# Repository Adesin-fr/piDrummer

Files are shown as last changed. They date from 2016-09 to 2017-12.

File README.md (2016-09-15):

# piDrummer

piDrummer is a DIY drum trigger device. it uses an Arduino and some basic components to get the signal from your pads (AKA triggers) and send them to a Raspberry Pi 3.

A Raspberry Pi 3 is used to play sounds according to the triggers you hit. 

Thanks to CPU power of a such board computer (4x1.2 Ghz), it is possible to play the best sound quality !

The rPi is also driving an ILI9341 TFT screen (320x240 pixels, can be found as cheap as 5$ on ebay ) and displays an interface that allows you to set up your different drum kits, the volume, sound effects (reverb, equalizer, etc...), and map each trigger to an instrument.

The goal is also to build an embedded linux, with the smallest possible kernel, allowing for very small boot time !

# piDrummer (Version Française)

piDrummer est un module de batterie électronique à fabriquer soi-même.

Il utilise un module Arduino et quelques composants pour récupérer le signal depuis les PADS (aussi appelés Triggers), et envoie ces informations à une carte Raspberry Pi 3.

La carte est alors utilisée pour jouer les sons en fonction des coups donnés.

Grâce à la puissance de calcul disponible sur la carte (4x1.2 Ghz), un rendu sonore de haute qualité est possible !

La carte rPi est aussi utilisée pour piloter un afficheur TFT (320x240 à base de puce ILI9341, qu'on peut acheter sur Ebay pour moins de 5€) afin de régler et choisir vos différents kits, le volume, les effets sonores (reverb, équaliseur, etc...) et mapper chaque trigger à un instrument.

Le but du projet est aussi de monter un système linux embarqué (linux Embedded) avec un noyau le plus léger possible, et un temps de démarrage le plus faible possible !

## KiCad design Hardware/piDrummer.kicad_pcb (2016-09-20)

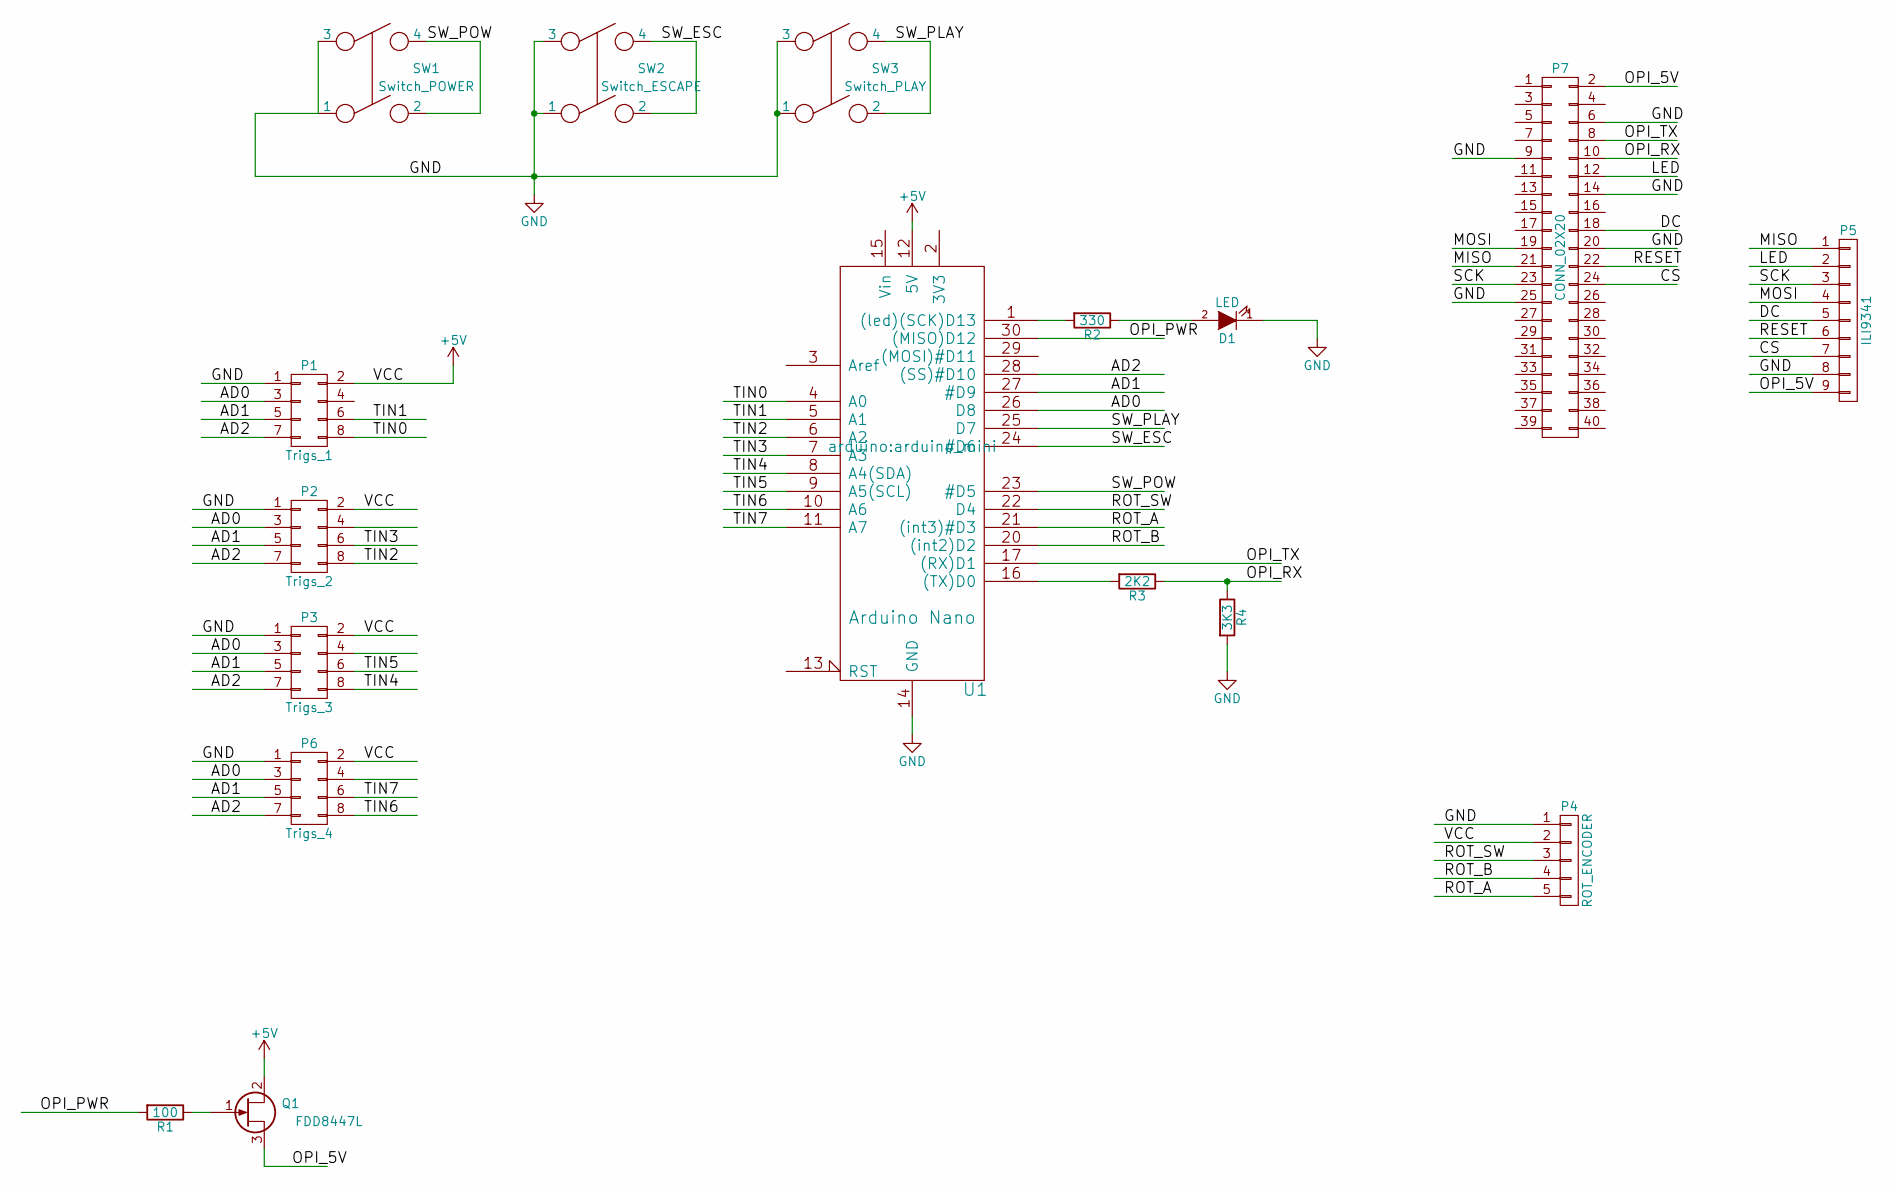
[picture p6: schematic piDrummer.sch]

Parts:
D1: LED; LED-3MM
P1: Trigs_1; Pin_Header_Straight_2x04
P2: Trigs_2; Pin_Header_Straight_2x04
P3: Trigs_3; Pin_Header_Straight_2x04
P4: ROT_ENCODER; Pin_Header_Straight_1x05
P5: ILI9341; Pin_Header_Straight_1x09
P6: Trigs_4; Pin_Header_Straight_2x04
P7: CONN_02X20; Pin_Header_Straight_2x20
Q1: FDD8447L; MOSFET_TO252
R1: 100; R4-LARGE_PADS
R2: 330; R4-LARGE_PADS
R3: 2K2; R4-LARGE_PADS
R4: 3K3; R4-LARGE_PADS
SW1: Switch_POWER; NetTie-III
SW2: Switch_ESCAPE; NetTie-III
SW3: Switch_PLAY; NetTie-III
U1: Arduino Nano; arduino_mini

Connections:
+5V: P1.2, P2.2, P3.2, P4.2, P6.2, Q1.2 (D), U1.12 (5V)
/AD0: P1.3, P2.3, P3.3, P6.3, U1.26 (D8)
/AD1: P1.5, P2.5, P3.5, P6.5, U1.27 (#D9)
/AD2: P1.7, P2.7, P3.7, P6.7, U1.28 ((SS)#D10)
/CS: P5.7, P7.24
/DC: P5.5, P7.18
/LED: P5.2, P7.12
/MISO: P5.1, P7.21
/MOSI: P5.4, P7.19
/OPI_5V: P5.9, P7.2, Q1.3 (S)
/OPI_PWR: R1.2, U1.30 ((MISO)D12)
/OPI_RX: P7.10, R3.1, R4.1
/OPI_TX: P7.8, U1.17 ((RX)D1)
/RESET: P5.6, P7.22
/ROT_A: P4.5, U1.21 ((int3)#D3)
/ROT_B: P4.4, U1.20 ((int2)D2)
/ROT_SW: P4.3, U1.22 (D4)
/SCK: P5.3, P7.23
/SW_ESC: SW2.2, SW2.4, U1.24 (#D6)
/SW_PLAY: SW3.2, SW3.4, U1.25 (D7)
/SW_POW: SW1.2, SW1.4, U1.23 (#D5)
/TIN0: P1.8, U1.4 (A0)
/TIN1: P1.6, U1.5 (A1)
/TIN2: P2.8, U1.6 (A2)
/TIN3: P2.6, U1.7 (A3)
/TIN4: P3.8, U1.8 (A4(SDA))
/TIN5: P3.6, U1.9 (A5(SCL))
/TIN6: P6.8, U1.10 (A6)
/TIN7: P6.6, U1.11 (A7)
GND: D1.1 (K), P1.1, P2.1, P3.1, P4.1, P5.8, P6.1, P7.6, P7.9, P7.14, P7.20, P7.25, R4.2, SW1.1, SW1.3, SW2.1, SW2.3, SW3.1, SW3.3, U1.14 (GND), U1.19 (GND)
unnamed: D1.2 (A), R2.1
unnamed: Q1.1 (G), R1.1
unnamed: R2.2, U1.1 ((led)(SCK)D13)
unnamed: R3.2, U1.16 ((TX)D0)

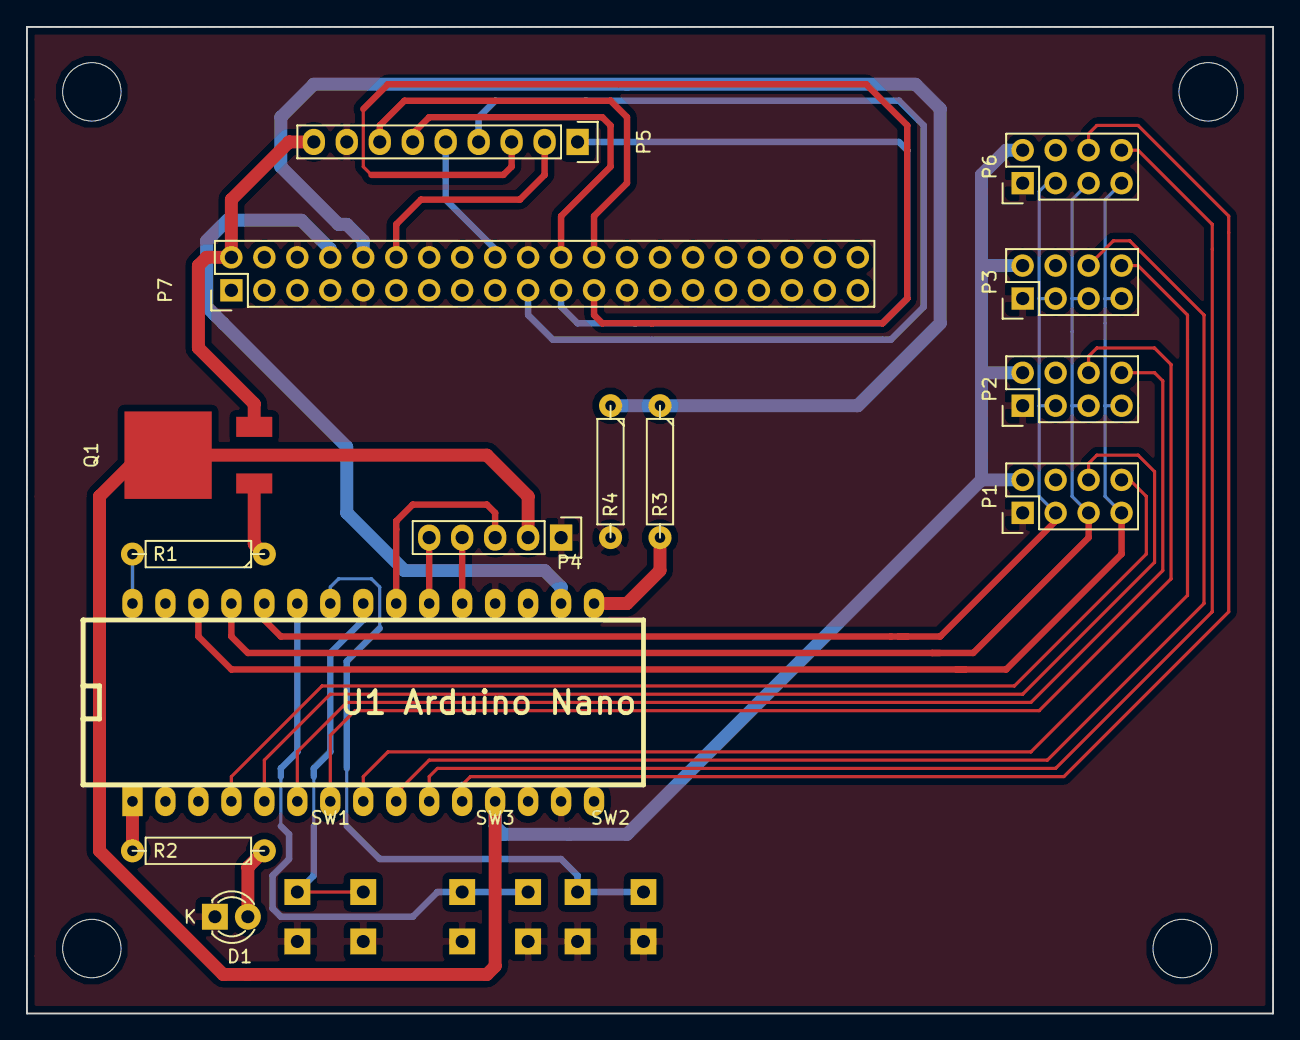
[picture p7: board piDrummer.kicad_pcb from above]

Board: 2 copper layers, 96.0 x 76.0 mm, 17 parts (0 on the bottom side), 34 nets.

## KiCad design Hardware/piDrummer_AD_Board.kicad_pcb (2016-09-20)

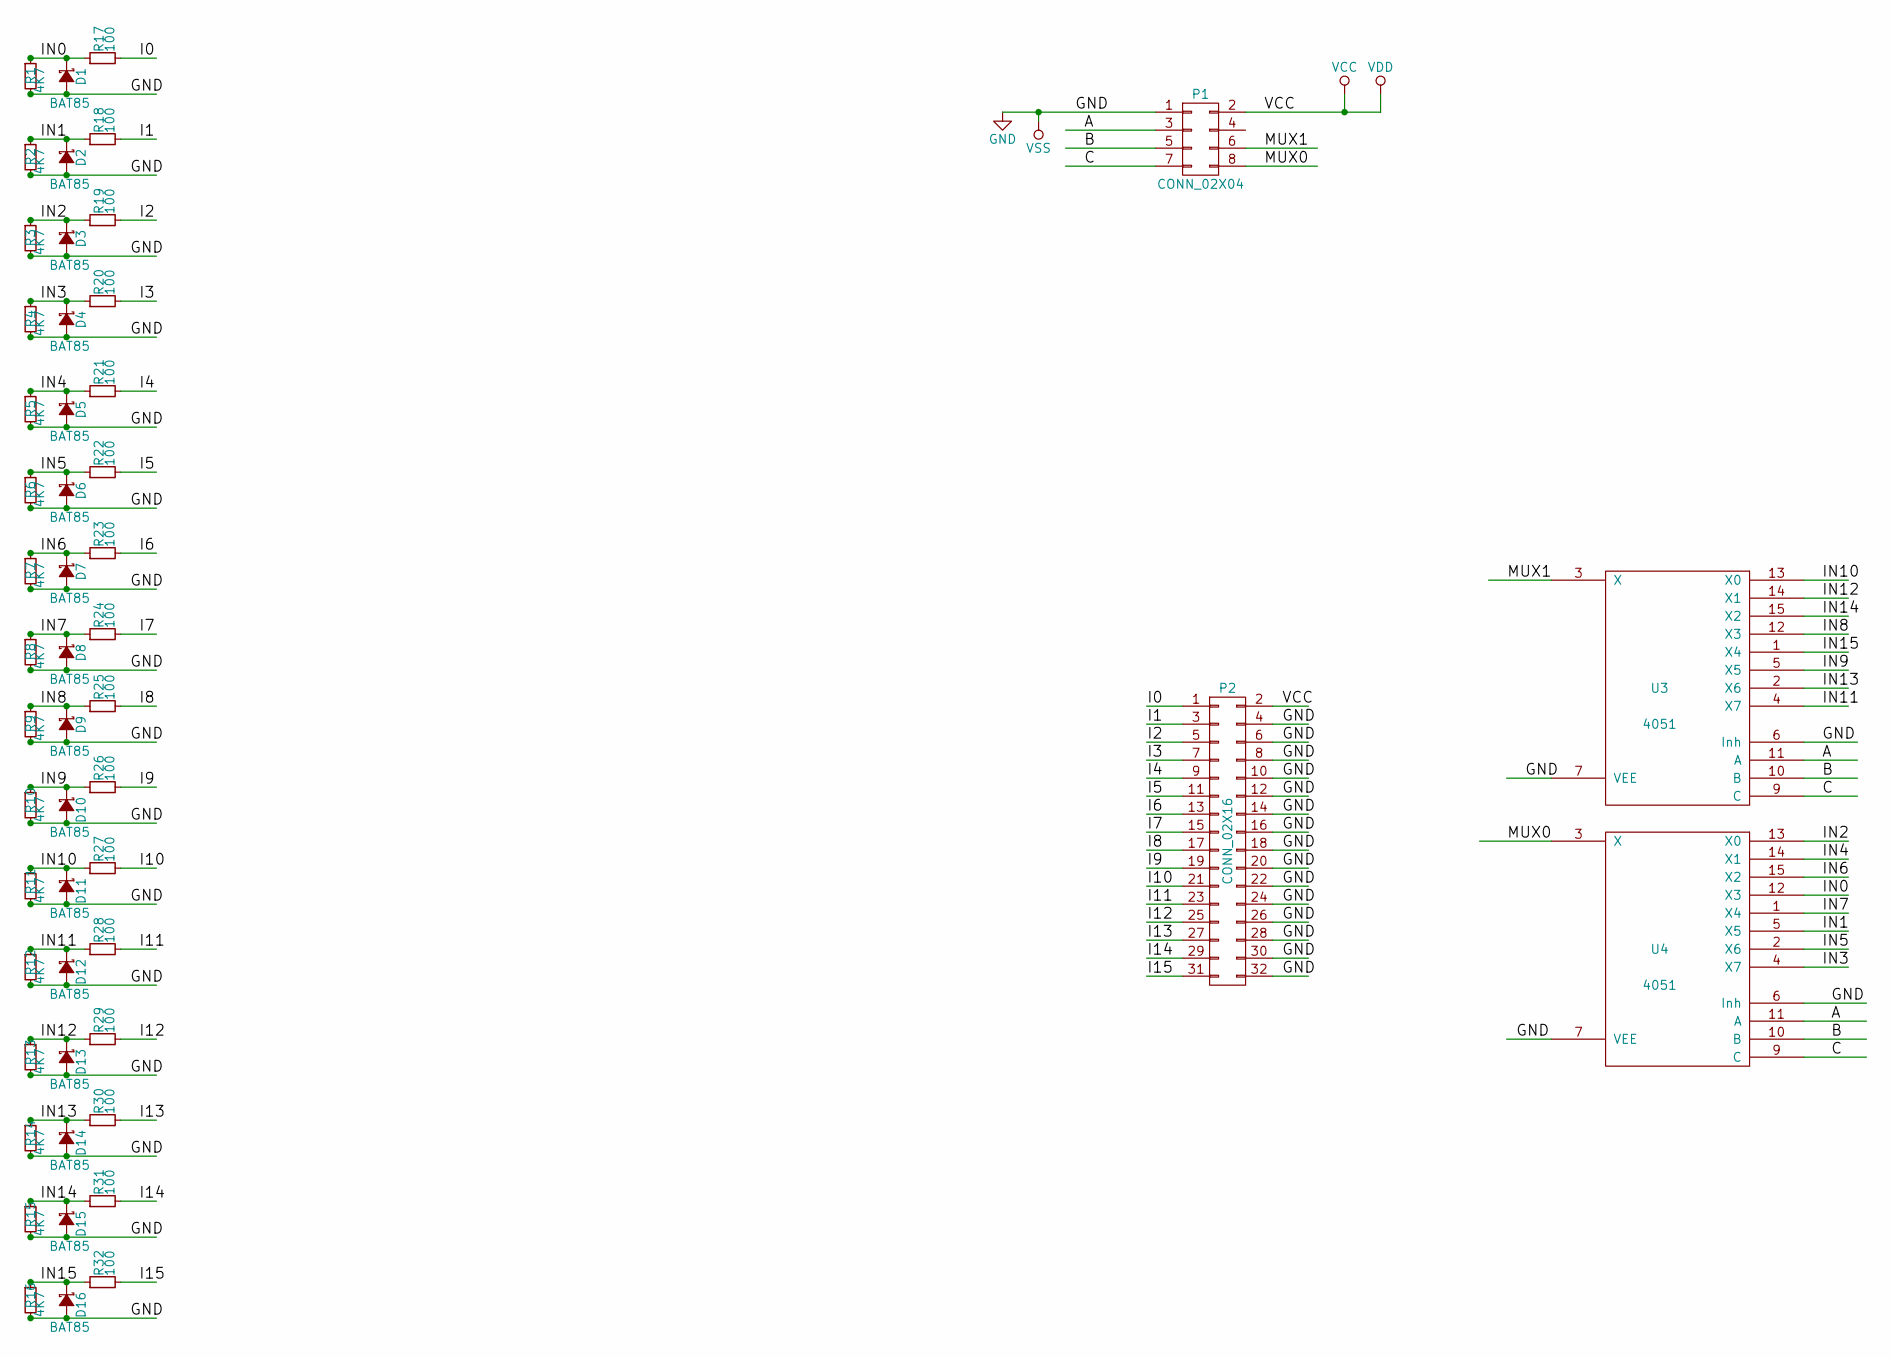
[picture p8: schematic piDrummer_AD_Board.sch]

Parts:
D1, D2, D3, D4, D5, D6, D7, D8, D9, D10, D11, D12, D13, D14, D15, D16: BAT85; Diode_DO-35_SOD27_Horizontal_RM10
P1: CONN_02X04; Header_Straight_8pins
P2: CONN_02X16; Header_Straight_32pins
R1, R2, R3, R4, R5, R6, R7, R8, R9, R10, R11, R12, R13, R14, R15, R16: 4K7; RES35
R17, R18, R19, R20, R21, R22, R23, R24, R25, R26, R27, R28, R29, R30, R31, R32: 100; RES35
U3, U4: 4051; DIP-16_W7.62mm_LongPads

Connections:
/A: P1.3, U3.11 (A), U4.11 (A)
/B: P1.5, U3.10 (B), U4.10 (B)
/C: P1.7, U3.9 (C), U4.9 (C)
/I0: P2.1, R17.2
/I1: P2.3, R18.2
/I2: P2.5, R19.2
/I3: P2.7, R20.2
/I4: P2.9, R21.2
/I5: P2.11, R22.2
/I6: P2.13, R23.2
/I7: P2.15, R24.2
/I8: P2.17, R25.2
/I9: P2.19, R26.2
/I10: P2.21, R27.2
/I11: P2.23, R28.2
/I12: P2.25, R29.2
/I13: P2.27, R30.2
/I14: P2.29, R31.2
/I15: P2.31, R32.2
/IN0: D1.1 (K), R1.1, R17.1, U4.12 (X3)
/IN1: D2.1 (K), R2.1, R18.1, U4.5 (X5)
/IN2: D3.1 (K), R3.1, R19.1, U4.13 (X0)
/IN3: D4.1 (K), R4.1, R20.1, U4.4 (X7)
/IN4: D5.1 (K), R5.1, R21.1, U4.14 (X1)
/IN5: D6.1 (K), R6.1, R22.1, U4.2 (X6)
/IN6: D7.1 (K), R7.1, R23.1, U4.15 (X2)
/IN7: D8.1 (K), R8.1, R24.1, U4.1 (X4)
/IN8: D9.1 (K), R9.1, R25.1, U3.12 (X3)
/IN9: D10.1 (K), R10.1, R26.1, U3.5 (X5)
/IN10: D11.1 (K), R11.1, R27.1, U3.13 (X0)
/IN11: D12.1 (K), R12.1, R28.1, U3.4 (X7)
/IN12: D13.1 (K), R13.1, R29.1, U3.14 (X1)
/IN13: D14.1 (K), R14.1, R30.1, U3.2 (X6)
/IN14: D15.1 (K), R15.1, R31.1, U3.15 (X2)
/IN15: D16.1 (K), R16.1, R32.1, U3.1 (X4)
/MUX0: P1.8, U4.3 (X)
/MUX1: P1.6, U3.3 (X)
GND: D1.2 (A), D2.2 (A), D3.2 (A), D4.2 (A), D5.2 (A), D6.2 (A), D7.2 (A), D8.2 (A), D9.2 (A), D10.2 (A), D11.2 (A), D12.2 (A), D13.2 (A), D14.2 (A), D15.2 (A), D16.2 (A), P1.1, P2.4, P2.6, P2.8, P2.10, P2.12, P2.14, P2.16, P2.18, P2.20, P2.22, P2.24, P2.26, P2.28, P2.30, P2.32, R1.2, R2.2, R3.2, R4.2, R5.2, R6.2, R7.2, R8.2, R9.2, R10.2, R11.2, R12.2, R13.2, R14.2, R15.2, R16.2, U3.6 (Inh), U3.7 (VEE), U3.8 (VSS), U4.6 (Inh), U4.7 (VEE), U4.8 (VSS)
VCC: P1.2, P2.2, U3.16 (VDD), U4.16 (VDD)

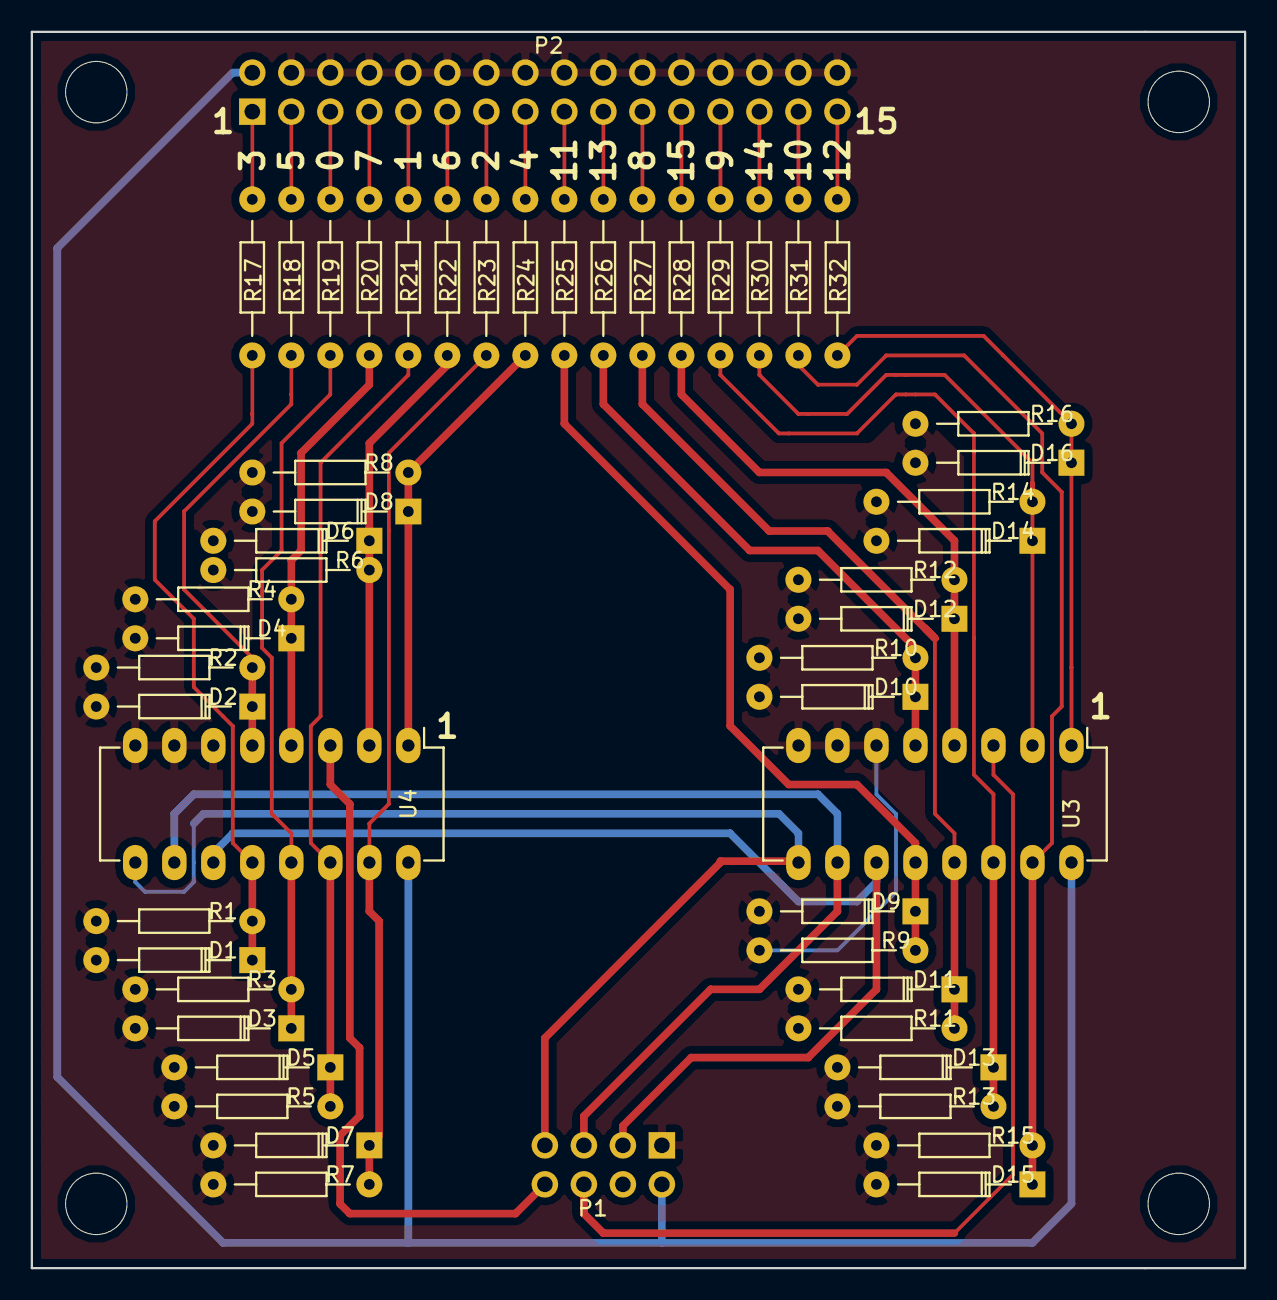
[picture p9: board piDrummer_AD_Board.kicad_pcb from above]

Board: 2 copper layers, 79.0 x 80.5 mm, 52 parts (0 on the bottom side), 39 nets.

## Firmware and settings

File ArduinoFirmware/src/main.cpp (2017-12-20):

#include <Arduino.h>
#include <EEPROM.h>
#include "piDrummer.h"
#include "encoder.h"

/*
 * POWER Button behavior :
 * 		When we power the arduino, we are on standby mode. > MOSFET is OFF, POWER LED is OFF
 *		If we push the power button :
 *			turn ON the MOSFET
 *			blink the LED until the OrangePI sends "ready status" and get parameters
 *		If we push the button before ready status : do nothing
 *		If we push the button after ready status :
 * 			blink led while not ready to poweroff (a few seconds)
 *			send POWEROFF event to OrangePI
 *			wait a few seconds and MOSFET OFF
 *		If receive a POWEROFF event from OrangePI :
 *			do POWEROFF sequence.
 *
 * TODO :
 * - Handle serial inputs to set parameters for each trigger.
	"CT",m_crossTalkGroup);
	"DT",m_dynamicTriggerPercent);
	"FS",m_footSplashSensitivity);
	"CR",m_ControllerResolution);
	"MG",m_muteGroup);
	"MT",m_FixedMaskTime);
	"TH",m_threshold);
	"TT",m_triggerType);
	"MV",m_maxValue);
 *
 * - Cymbal 3 zones w/ Chocke :  ?
 * 		> Voir fichier cy-15r.gif pour cablage & principe
 * 			3 entrées :
 * 			> 1 piezo = velocité
 * 			> 1 switch bell / 1 switch underside (choke) en parallele
 * 				> Maintient appuyé sur switch = choke
 * 			> 1 switch edge
 *
 * 		> Frappe courte sur switch bell/edge = envoi note bell/edge
 *
 * - Pour les entrées SWITCH : activer resistance PULL-UP : digitalWrite(A0, HIGH);
 * - Parametre par entree : type PAD / SWITCH
 * - FAIRE UN TEST AVEC TOUTES LES PULLUP ?
 * - Implement HiHat "Chicks" (record time between pedal value variation )
 * - Implement Cross-Talk groups (i.e. for cymbal dual zone handling)
 */

Trigger trigArray[NB_ANALOG_CHANNELS];

int anaRead=0;
int lastHitRawValue;
byte midiVelocity=0;
byte lastHitTrigger=0;
byte HiHatPedalChannel=16;
byte HiHatCymbalChannel=17;
byte HiHatValue=0;
byte prevHiHatValue;
bool isPowerON=false;
bool isOPiReady=false;
bool PowerLedState=false;
bool PowerOffAsked=false;
unsigned long lastPowerButtonPress=0;
unsigned long lastPowerLedBlinkTime=0;
unsigned long PowerOffAskTime=0;
unsigned int encoder0Pos = 0;
int oldEncoderPos = 0;

void setup() {
	Serial.begin(115200);

	// Faster ADC readings :
	setADCSampleRate();


	pinMode(MUXER_AD0, OUTPUT)   ; // Muxer address select PINs
	pinMode(MUXER_AD1, OUTPUT)   ; // Muxer address select PINs
	pinMode(MUXER_AD2, OUTPUT)   ; // Muxer address select PINs
	pinMode(encoderPinA, INPUT_PULLUP);
	pinMode(encoderPinB, INPUT_PULLUP);
	pinMode(EnterPushButton, INPUT_PULLUP);
	pinMode(EscapePushButton, INPUT_PULLUP);
	pinMode(POWER_BUTTON_PIN, INPUT_PULLUP);


		/*
		// Perform auto-threshold

		// Read each channel 20 times, sum the values, then divide them to get the average value:
		long readValue[NB_ANALOG_CHANNELS];
		for (int i=1; i<=NB_ANALOG_CHANNELS; i++){
			readValue[i]=0;
		}

		for (int count=0; count<20; count++) {
			for (int i=0; i<NB_ANALOG_CHANNELS; i++){
				// Read the channel and add th result to the array :
				byte tempValue=readChannel(i);
				readValue[i]+=tempValue;
				// Wait 10 ms between each channel reading...
				delay (10);
			}
		}

		// Once we're done with readings, divide the values and store them in config :
		for (int i=0; i<NB_ANALOG_CHANNELS; i++){
			// Read the channel and add th result to the array :
			if (i != HiHatPedalChannel){
				// Don't apply threshold to hihat channel
				byte tempValue=readValue[i] / 20;
				trigArray[i].thresHold = tempValue;
			}
		}
		*/



		for (int i=0; i<NB_ANALOG_CHANNELS; i++){

			trigArray[i].thresHold = 25;
			trigArray[i].debounce=20;
			trigArray[i].DynamicThreshold=20;
			trigArray[i].maxValue=1023;
		}


}




void loop() {


		doAnalogReadings();

		// Deal with Encoder values :
		HandleEncoderChange();

	// Deal with trigger events only if OPi is Ready !
	if (isOPiReady){

		// Deal with Encoder values :
		HandleEncoderChange();

		// Deal with inputs :
		doAnalogReadings();

		// Reset Threshold values :
		ResetThresholdValues();
	}

	// Handle POWER button  :
	if (lastPowerButtonPress+100 < millis() && digitalRead(POWER_BUTTON_PIN)==LOW){
		Serial.println("Pow !");
		lastPowerButtonPress = millis();
		// Button was pressed : do something !
		if (isPowerON==false){
			// We are not powered , let's go ON !
			isPowerON=true;
			// Turn on the led...
			PowerLedState=true;
			digitalWrite(POWER_MOSFET_PIN, HIGH);
			digitalWrite(POWER_LED_PIN, PowerLedState);
		}else{
			// We are powered , let's go OFF (if we can...)
			// If we are powered ON, but the OrangiPI is not ready, do nothing...
			if (isOPiReady){
				isOPiReady=false;
				PowerOffAsked=true;
				// Since isOpiReady==false AND isPowerON==true, the LED should start blinking !
				// Send the OPi a signal to ask him shut-off...
				// Equivalent to F12 key value !
				serialOut(MSGTYPE_KEYPRESS_VALUE, 255, 38, 0);
			}
		}
	}

	// Should we blink the led ?
	if (isPowerON && !isOPiReady && lastPowerLedBlinkTime+1000 < millis()){
			PowerLedState=!PowerLedState;
			digitalWrite(POWER_LED_PIN, PowerLedState);
	}

	// Should we shut power to the oPi ?
	if (PowerOffAskTime+10000 < millis() && PowerOffAsked==true){
		PowerOffAsked=false;
		isPowerON=false;
		// Switch off power supply now :
		digitalWrite(POWER_MOSFET_PIN, LOW);
	}

}

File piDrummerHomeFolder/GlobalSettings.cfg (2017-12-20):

AlsaBufferSize = 2048;
numTriggerInput = 32;
GlobalVolume = 32;
AutoPowerOffDelay = 0;
ReverbDelay = 0;
PowerOnKitName = "Basic Kit";
SerialDevice = "";
GlobalFadeOutTime = 0.5;
PlaySampleOnSettingChange = true;
RotaryKnobInversion = false;
RotaryKnobAction = 2;
EQLowFrequency = 0;
EQMidFrequency = 0;
EQHiFrequency = 0;
EQLowGain = 0.0;
EQMidGain = 0.0;
EQHiGain = 0.0;
Triggers = ( 
  {
    InputNumber = 0;
    Name = "Snare Center";
    TriggerType = 0;
    Threshold = 0;
    DynamicTriggerPercent = 20;
    ControllerResolution = 16;
    PositionalSensing = 0;
    MuteGroup = 0;
    CrossTalkGroup = 0;
    FixedMaskTime = 10;
    MaxValue = 1024;
    FootSplashSensitivity = 4;
    SignalCurveType = 0;
  }, 
  {
    InputNumber = 1;
    Name = "Snare Edge";
    TriggerType = 0;
    Threshold = 0;
    DynamicTriggerPercent = 20;
    ControllerResolution = 16;
    PositionalSensing = 0;
    MuteGroup = 0;
    CrossTalkGroup = 0;
    FixedMaskTime = 10;
    MaxValue = 1024;
    FootSplashSensitivity = 4;
    SignalCurveType = 0;
  }, 
  {
    InputNumber = 2;
    Name = "Tom 1 Center";
    TriggerType = 0;
    Threshold = 0;
    DynamicTriggerPercent = 20;
    ControllerResolution = 16;
    PositionalSensing = 0;
    MuteGroup = 0;
    CrossTalkGroup = 0;
    FixedMaskTime = 10;
    MaxValue = 1024;
    FootSplashSensitivity = 4;
    SignalCurveType = 0;
  }, 
  {
    InputNumber = 3;
    Name = "Tom 1 Edge";
    TriggerType = 0;
    Threshold = 0;
    DynamicTriggerPercent = 20;
    ControllerResolution = 16;
    PositionalSensing = 0;
    MuteGroup = 0;
    CrossTalkGroup = 0;
    FixedMaskTime = 10;
    MaxValue = 1024;
    FootSplashSensitivity = 4;
    SignalCurveType = 0;
  }, 
  {
    InputNumber = 4;
    Name = "Tom 2 Center";
    TriggerType = 0;
    Threshold = 0;
    DynamicTriggerPercent = 20;
    ControllerResolution = 16;
    PositionalSensing = 0;
    MuteGroup = 0;
    CrossTalkGroup = 0;
    FixedMaskTime = 10;
    MaxValue = 1024;
    FootSplashSensitivity = 4;
    SignalCurveType = 0;
  }, 
  {
    InputNumber = 5;
    Name = "Tom 2 Edge";
    TriggerType = 0;
    Threshold = 0;
    DynamicTriggerPercent = 20;
    ControllerResolution = 16;
    PositionalSensing = 0;
    MuteGroup = 0;
    CrossTalkGroup = 0;
    FixedMaskTime = 10;
    MaxValue = 1024;
    FootSplashSensitivity = 4;
    SignalCurveType = 0;
  }, 
  {
    InputNumber = 6;
    Name = "Tom 3 Center";
    TriggerType = 0;
    Threshold = 0;
    DynamicTriggerPercent = 20;
    ControllerResolution = 16;
    PositionalSensing = 0;
    MuteGroup = 0;
    CrossTalkGroup = 0;
    FixedMaskTime = 10;
    MaxValue = 1024;
    FootSplashSensitivity = 4;
    SignalCurveType = 0;
  }, 
  {
    InputNumber = 7;
    Name = "Tom 3 Edge";
    TriggerType = 0;
    Threshold = 0;
    DynamicTriggerPercent = 20;
    ControllerResolution = 16;
    PositionalSensing = 0;
    MuteGroup = 0;
    CrossTalkGroup = 0;
    FixedMaskTime = 10;
    MaxValue = 1024;
    FootSplashSensitivity = 4;
    SignalCurveType = 0;
  }, 
  {
    InputNumber = 8;
    Name = "Kick";
    TriggerType = 0;
    Threshold = 0;
    DynamicTriggerPercent = 20;
    ControllerResolution = 16;
    PositionalSensing = 0;
    MuteGroup = 0;
    CrossTalkGroup = 0;
    FixedMaskTime = 10;
    MaxValue = 1024;
    FootSplashSensitivity = 4;
    SignalCurveType = 0;
  }, 
  {
    InputNumber = 9;
    Name = "Not Used";
    TriggerType = 0;
    Threshold = 0;
    DynamicTriggerPercent = 20;
    ControllerResolution = 16;
    PositionalSensing = 0;
    MuteGroup = 0;
    CrossTalkGroup = 0;
    FixedMaskTime = 10;
    MaxValue = 1024;
    FootSplashSensitivity = 4;
    SignalCurveType = 0;
  }, 
  {
    InputNumber = 10;
    Name = "HiHat Pedal";
    TriggerType = 0;
    Threshold = 0;
    DynamicTriggerPercent = 20;
    ControllerResolution = 16;
    PositionalSensing = 0;
    MuteGroup = 0;
    CrossTalkGroup = 0;
    FixedMaskTime = 10;
    MaxValue = 1024;
    FootSplashSensitivity = 4;
    SignalCurveType = 0;
  }, 
  {
    InputNumber = 11;
    Name = "Unused";
    TriggerType = 0;
    Threshold = 0;
    DynamicTriggerPercent = 20;
    ControllerResolution = 16;
    PositionalSensing = 0;
    MuteGroup = 0;
    CrossTalkGroup = 0;
    FixedMaskTime = 10;
    MaxValue = 1024;
    FootSplashSensitivity = 4;
    SignalCurveType = 0;
  }, 
  {
    InputNumber = 12;
    Name = "HiHat Edge";
    TriggerType = 0;
    Threshold = 0;
    DynamicTriggerPercent = 20;
    ControllerResolution = 16;
    PositionalSensing = 0;
    MuteGroup = 0;
    CrossTalkGroup = 0;
    FixedMaskTime = 10;
    MaxValue = 1024;
    FootSplashSensitivity = 4;
    SignalCurveType = 0;
  }, 
  {
    InputNumber = 13;
    Name = "Unused";
    TriggerType = 0;
    Threshold = 0;
    DynamicTriggerPercent = 20;
    ControllerResolution = 16;
    PositionalSensing = 0;
    MuteGroup = 0;
    CrossTalkGroup = 0;
    FixedMaskTime = 10;
    MaxValue = 1024;
    FootSplashSensitivity = 4;
    SignalCurveType = 0;
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

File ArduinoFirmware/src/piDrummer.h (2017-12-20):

#ifndef PIDRUMMER_H_
#define PIDRUMMER_H_


#include <Arduino.h>
#include <avr/pgmspace.h>
#include "piDrummerPins.h"


// Setting ADC frequency reading :
// To disable, just comment the following line :
// Only one of 4 lines must be un-commented !
// If more than 1 is uncommented, only last one will be used.
// BEWARE that setting a higher frequency than 1MHZ can cause ADC reading errors.
//

// #define ADC_500KHZ 1
#define ADC_1MHZ 1
// #define ADC_2MHZ 1
// #define ADC_4MHZ 1

// Prototypes :
void serialOut(byte MessageType, byte InputNumber, byte MessageValue, byte Modifier);


struct Trigger {
	unsigned long lastRead;
	byte thresHold;
	byte debounce;
	byte DynamicThreshold;
	long previousReadValue;
	bool rising;
	long maxValue;
	bool thresHoldNeedReset;
	byte SetupThresHold;
	long lastZeroTime;
};

extern Trigger trigArray[NB_ANALOG_CHANNELS];
extern byte HiHatPedalChannel;
extern byte HiHatCymbalChannel;
extern int anaRead;
extern int lastHitRawValue;

extern byte HiHatValue;
extern byte prevHiHatValue;
extern byte lastHitTrigger;
extern bool lcdNeedRefresh;
extern byte midiVelocity;


/*
 *
 *  Analog stuff :
 *
*/

long readChannel(byte ChanNumber){
	long val=0;
	/*
	 *  Each Analog Input have a CD4051 tied
	 *  When we need to switch the channel input, we do it for all CD4015,
	 *  and then we read the correct input .
	 *  Since we got 8 input channels * 8 CD4051 = 64 total input triggers !
	 */

	digitalWrite(MUXER_AD0, bitRead(ChanNumber,0));
	digitalWrite(MUXER_AD1, bitRead(ChanNumber,1));
	digitalWrite(MUXER_AD2, bitRead(ChanNumber,2));

	// The CD4051 takes 720ns max (0.72µs) to switch channel, so let's wait a bit (a microsecond should be enought) :
	delayMicroseconds(1);

	// Do stuff to switch CD4051 channels :
	if (ChanNumber<8){
		val = analogRead(A0);
	}else if (ChanNumber<16){
		val = analogRead(A1);
	}else if (ChanNumber<24){
		val = analogRead(A2);
	}else if (ChanNumber<32){
		val = analogRead(A3);
	}else if (ChanNumber<40){
		val = analogRead(A4);
	}else if (ChanNumber<48){
		val = analogRead(A5);
	}else if (ChanNumber<56){
		val = analogRead(A6);
	}else{
		val = analogRead(A7);
	}

	return val;
}



void doAnalogReadings(){

	for (int i=0; i<NB_ANALOG_CHANNELS; i++){
//	for (int i=0; i<1; i++){
		if (i == HiHatPedalChannel){
			// Read the hihat channel different way:
			anaRead = readChannel(i) ;
			// 32 steps is faaaaaaar enought for a hihat pedal !
			HiHatValue = map ( anaRead, 0, 1024, 0, 32);
			// Remap to 127 values
			HiHatValue = map ( HiHatValue , 0, 32, 0, 127);
			if (prevHiHatValue != HiHatValue){
				prevHiHatValue = HiHatValue;
				// Send MIDI CC
//				serialOut(MSGTYPE_CONTROL_VALUE, i, HiHatValue);
			}
		}else{
				// Read the value of the input:
				anaRead = readChannel(i) ;


				if (anaRead > trigArray[i].thresHold) {
						// Seems we did passed the end of peak, so send the previousReadValue :
					if (trigArray[i].previousReadValue > anaRead && trigArray[i].rising==true){

						if (millis() > trigArray[i].lastRead + trigArray[i].debounce){

							// Since we passed the peak , keep the timestamp for retriggering
							trigArray[i].lastRead=millis();
							lastHitRawValue = trigArray[i].previousReadValue;

							if (anaRead > trigArray[i].maxValue){
								trigArray[i].maxValue= anaRead ;
							}

							// Set the dynamic threshold
							trigArray[i].thresHold=trigArray[i].previousReadValue*trigArray[i].DynamicThreshold/100;
							trigArray[i].thresHoldNeedReset=true;


							// TODO : Should we send RAW values and parse them on oPi side ?

							midiVelocity = map ( trigArray[i].previousReadValue, 0, trigArray[i].maxValue, 0, 127);
							if (midiVelocity==0){
								midiVelocity=1;
							}
							if (midiVelocity>127){
								midiVelocity=127;
							}

							serialOut(MSGTYPE_TRIGGER_VALUE, i, midiVelocity, 127);
/*
							Serial.print("New Thr : ");
							Serial.print(trigArray[i].thresHold);

							Serial.print(" Vel : ");
							Serial.print(midiVelocity);

							Serial.print(" An : ");
							Serial.print(anaRead);

							Serial.print(" Pv : ");
							Serial.print(trigArray[i].previousReadValue);

							Serial.print(" Pk time : ");
							// Calculate peak delay time : difference between last zero value and now.
							long pk = (micros() - trigArray[i].lastZeroTime)/100;
							Serial.println(pk);
*/

							lastHitTrigger=i;
							trigArray[i].rising=false;
						}

					}else if (trigArray[i].previousReadValue < anaRead){
						// last value is smaller than current, We're rising !:
						trigArray[i].rising=true;

					}

					// Store the previous read value, to compare to the next value.
					trigArray[i].previousReadValue = anaRead;
				}else{
					trigArray[i].lastZeroTime=micros();
					trigArray[i].previousReadValue =0;
				}
		}

	}
}

void ResetThresholdValues(){
			// Set the dynamic threshold
	for (int i=1; i<=NB_ANALOG_CHANNELS; i++){
		if (trigArray[i].thresHoldNeedReset==true && millis() > trigArray[i].lastRead){
			trigArray[i].thresHold=trigArray[i].SetupThresHold;
			trigArray[i].thresHoldNeedReset=false;
		}
	}
}



void serialOut(byte MessageType, byte InputNumber, byte MessageValue, byte Modifier){
	Serial.write(MessageType);
	Serial.write(InputNumber);
	Serial.write(MessageValue);
	Serial.write(Modifier);
	Serial.write(0x0A); 		// Message END
}


void setADCSampleRate(){


	// defines for setting and clearing register bits
	#ifndef cbi
		#define cbi(sfr, bit) (_SFR_BYTE(sfr) &= ~_BV(bit))
	#endif
	#ifndef sbi
		#define sbi(sfr, bit) (_SFR_BYTE(sfr) |= _BV(bit))
	#endif

	#ifdef ADC_500KHZ
		// set prescale to 32
		sbi(ADCSRA,ADPS2) ;
		cbi(ADCSRA,ADPS1) ;
		sbi(ADCSRA,ADPS0) ;
	#endif


	#ifdef ADC_1MHZ
		// set prescale to 16
		sbi(ADCSRA,ADPS2) ;
		cbi(ADCSRA,ADPS1) ;
		cbi(ADCSRA,ADPS0) ;
	#endif

	#ifdef ADC_2MHZ
		// set prescale to 8
		cbi(ADCSRA,ADPS2) ;
		sbi(ADCSRA,ADPS1) ;
		sbi(ADCSRA,ADPS0) ;
	#endif

	#ifdef ADC_4MHZ
		// set prescale to 4
		cbi(ADCSRA,ADPS2) ;
		sbi(ADCSRA,ADPS1) ;
		cbi(ADCSRA,ADPS0) ;
	#endif

}

#endif /* PIDRUMMER_H_ */

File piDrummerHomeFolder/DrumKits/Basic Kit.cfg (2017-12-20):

DrumKitName = "Basic Kit";
Components = ( 
  {
    triggerNumber = 0;
    instrumentName = "SMD RimShot_Str_HyB1";
    replayGain = 1.0;
    pitch = 1.0;
    balance = 0.0;
  }, 
  {
    triggerNumber = 1;
    instrumentName = "RimShot_Stereo";
    replayGain = 1.0;
    pitch = 1.0;
    balance = 0.0;
  }, 
  {
    triggerNumber = 2;
    instrumentName = "";
    replayGain = 1.0;
    pitch = 1.0;
    balance = 0.0;
  }, 
  {
    triggerNumber = 3;
    instrumentName = "";
    replayGain = 1.0;
    pitch = 1.0;
    balance = 0.0;
  }, 
  {
    triggerNumber = 4;
    instrumentName = "";
    replayGain = 1.0;
    pitch = 1.0;
    balance = 0.0;
  }, 
  {
    triggerNumber = 5;
    instrumentName = "";
    replayGain = 1.0;
    pitch = 1.0;
    balance = 0.0;
  }, 
  {
    triggerNumber = 6;
    instrumentName = "";
    replayGain = 1.0;
    pitch = 1.0;
    balance = 0.0;
  }, 
  {
    triggerNumber = 7;
    instrumentName = "";
    replayGain = 1.0;
    pitch = 1.0;
    balance = 0.0;
  }, 
  {
    triggerNumber = 8;
    instrumentName = "Kik_Stereo";
    replayGain = 1.0;
    pitch = 1.0;
    balance = 0.0;
  }, 
  {
    triggerNumber = 9;
    instrumentName = "";
    replayGain = 1.0;
    pitch = 1.0;
    balance = 0.0;
  }, 
  {
    triggerNumber = 10;
    instrumentName = "";
    replayGain = 1.0;
    pitch = 1.0;
    balance = 0.0;
  }, 
  {
    triggerNumber = 11;
    instrumentName = "";
    replayGain = 1.0;
    pitch = 1.0;
    balance = 0.0;
  }, 
  {
    triggerNumber = 12;
    instrumentName = "";
    replayGain = 1.0;
    pitch = 1.0;
    balance = 0.0;
  }, 
  {
    triggerNumber = 13;
    instrumentName = "";
    replayGain = 1.0;
    pitch = 1.0;
    balance = 0.0;
  }, 
  {
    triggerNumber = 14;
    instrumentName = "";
    replayGain = 1.0;
    pitch = 1.0;
    balance = 0.0;
  }, 
  {
    triggerNumber = 15;
    instrumentName = "";
    replayGain = 1.0;
    pitch = 1.0;
    balance = 0.0;
  }, 
  {
    triggerNumber = 16;
    instrumentName = "";
    replayGain = 1.0;
    pitch = 1.0;
    balance = 0.0;
  }, 
  {
    triggerNumber = 17;
    instrumentName = "";
    replayGain = 1.0;
    pitch = 1.0;
    balance = 0.0;
  }, 
  {
    triggerNumber = 18;
    instrumentName = "";
    replayGain = 1.0;
    pitch = 1.0;
    balance = 0.0;
  }, 
  {
    triggerNumber = 19;
    instrumentName = "";
    replayGain = 1.0;
    pitch = 1.0;
    balance = 0.0;
  }, 
  {
    triggerNumber = 20;
    instrumentName = "";
    replayGain = 1.0;
    pitch = 1.0;
    balance = 0.0;
  }, 
  {
    triggerNumber = 21;
    instrumentName = "";
    replayGain = 1.0;
    pitch = 1.0;
    balance = 0.0;
  }, 
  {
    triggerNumber = 22;
    instrumentName = "";
    replayGain = 1.0;
    pitch = 1.0;
    balance = 0.0;
  }, 
  {
    triggerNumber = 23;
    instrumentName = "";
    replayGain = 1.0;
    pitch = 1.0;
    balance = 0.0;
  }, 
  {
    triggerNumber = 24;
    instrumentName = "";
    replayGain = 1.0;
    pitch = 1.0;
    balance = 0.0;
  }, 
  {
    triggerNumber = 25;
    instrumentName = "";
    replayGain = 1.0;
    pitch = 1.0;
    balance = 0.0;
  }, 
  {
    triggerNumber = 26;
    instrumentName = "";
    replayGain = 1.0;
    pitch = 1.0;
    balance = 0.0;
  }, 
  {
    triggerNumber = 27;
    instrumentName = "";
    replayGain = 1.0;
    pitch = 1.0;
    balance = 0.0;
  }, 
  {
    triggerNumber = 28;
    instrumentName = "";
    replayGain = 1.0;
    pitch = 1.0;
    balance = 0.0;
  }, 
  {
    triggerNumber = 29;
    instrumentName = "";
    replayGain = 1.0;
    pitch = 1.0;
    balance = 0.0;
  }, 
  {
    triggerNumber = 30;
    instrumentName = "";
    replayGain = 1.0;
    pitch = 1.0;
    balance = 0.0;
  }, 
  {
    triggerNumber = 31;
    instrumentName = "";
    replayGain = 1.0;
    pitch = 1.0;
    balance = 0.0;
  } );

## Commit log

2016-07-20 Added current UI work
2016-07-28 Added TextLabel Class Redesigned serial port handling to set blocking event of 10ms in each loop. The blocking event exits if data is not available, or if data is there ! This drastically lower CPU u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
2016-07-29 Many small changes Using libsndfile to load samples. This allow us to load many more file formats (eg flac; etc...) BEWARE that using anything else than uncompressed file format will make loading slo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
2016-08-04 Moved screen drawing function to a different thread. Since this function was eating about 5-6ms, this should lower the latency.
2016-08-05 Changed the multithreading gear : SDL doesn't like to be in a separate thread, so the "serial handling" stuff is now runned in a different thread. Running with an Alsa buffer size of 512 works great 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
2016-08-05 Added a "Font Store" to keep fonts loaded between each call Fixed samples loading with libsndfile
2016-08-10 Added Metronome class Added support for round robin samples !
2016-09-15 Moved software in subfolder... Added hardware schematics !
    [piDrummer.kicad_pcb, piDrummer.sch, piDrummer_AD_Board.kicad_pcb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]
2016-09-20 Added gerber output for hardware
    [piDrummer-B.Cu.gbl, piDrummer-B.Mask.gbs, piDrummer-B.SilkS.gbo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]
2017-12-15 Added splash files and conversion tool.
    [piDrummer.sch, piDrummer_AD_Board.sch]
2017-12-17 Added Arduino Firmware
    [piDrummer.sch, piDrummer_AD_Board.sch]
2017-12-19 Changed arduino firmware to be compiled with Atom.io and platform.io
2017-12-20 Added Home folder (~/.piDrummer) and resource contents.
    [Basic Kit.cfg, GlobalSettings.cfg, Jazz Kit.cfg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]
